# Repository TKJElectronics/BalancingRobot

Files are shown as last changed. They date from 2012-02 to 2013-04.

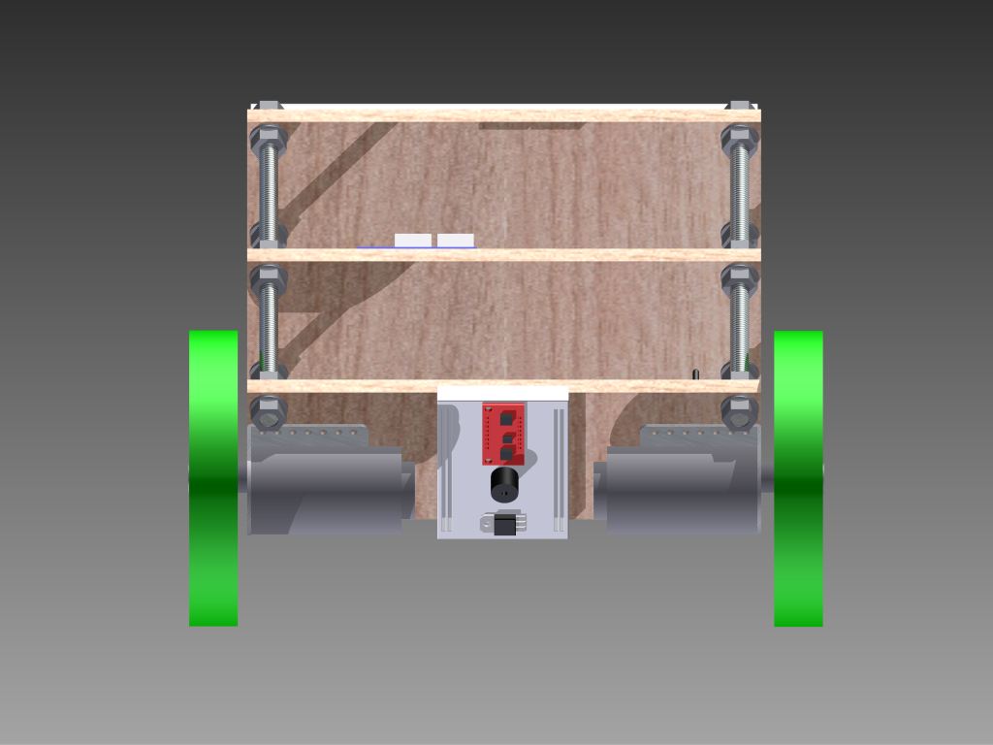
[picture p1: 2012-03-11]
3D Model/Rendered images/Back bottom.jpg

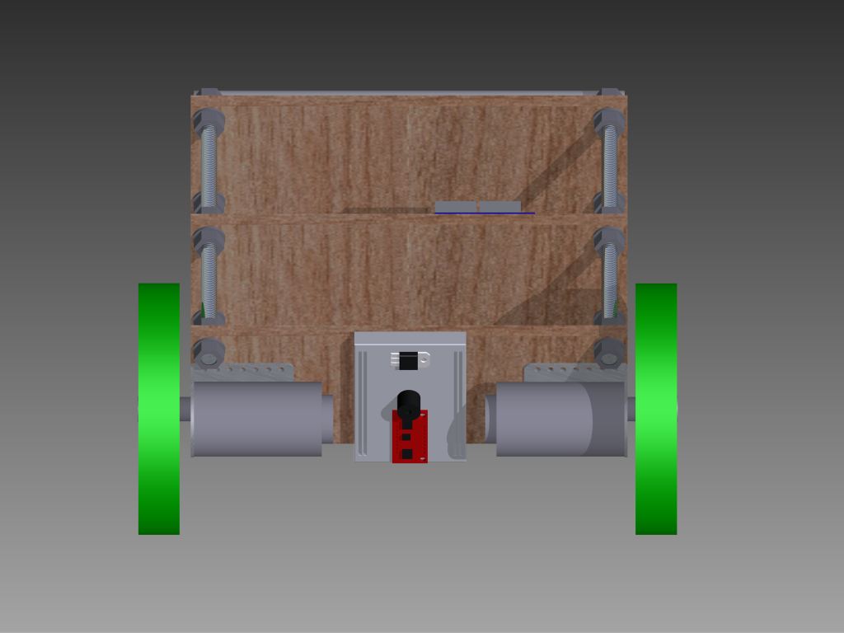
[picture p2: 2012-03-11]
3D Model/Rendered images/Front bottom.jpg

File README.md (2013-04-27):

# This project is deprecated

This project is no longer maintained as I will instead focus on a Balancing robot kit, the Balanduino. For more information see the new repository: <https://github.com/TKJElectronics/Balanduino> and the Kickstarter campaign: <http://www.kickstarter.com/projects/tkjelectronics/balanduino-balancing-robot-kit>.

<br>

The code is released under the GNU General Public License.
Developed by Kristian Lauszus

This is the code for my balancing robot/segway. It's made for the mbed board, but can easily be ported to other microcontrollers like the Arduino - see the Arduino version of the code: <https://github.com/TKJElectronics/BalancingRobotArduino>.

The code is also published on the mbed site: <http://mbed.org/users/Lauszus/programs/BalancingRobotPS3>.

I use a [6DOF IMU from Sparkfun](http://www.sparkfun.com/products/10010), I only use 1 of the gyro axis though.
For more info about calculating the pitch and the Kalman filter see my post at the Arduino forum: <http://arduino.cc/forum/index.php/topic,58048.0.html>.

To steer the robot, I use an Arduino with a [USB Host Shield](http://www.circuitsathome.com/products-page/arduino-shields/usb-host-shield-2-0-for-arduino/) on top together with my [PS3 Controller Bluetooth Library](https://github.com/felis/USB_Host_Shield_2.0/blob/master/PS3BT.cpp) for Arduino. The code for the remote can be found at my other repository: <https://github.com/TKJElectronics/BalancingRobotRemote>.

For information about the hardware, see the wiki: <https://github.com/TKJElectronics/BalancingRobot/wiki/Hardware>.

For more information see my blog post at <http://blog.tkjelectronics.dk/2012/03/the-balancing-robot/> or send me an email at: <kristianl@tkjelectronics.dk>.

Also check out the Youtube video of it in action: <http://www.youtube.com/watch?v=N28C_JqVhGU>.

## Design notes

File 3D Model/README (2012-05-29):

The code is released under the GNU General Public License.

This is the 3D model of my robot made in Autodesk Inventor 2012. See the folder "Rendered images" for images of the model.

The 3D model can also be viewed at the following site: http://grabcad.com/library/balancing-robot.

The Arduino board were made by the user "wam" at the Arduino forum: http://www.arduino.cc/cgi-bin/yabb2/YaBB.pl?num=1288144315/all.

The mbed board were made by Hugo Stoutjesdijk.

And the XBee module were made by Russell Donovan and downloaded from: http://grabcad.com/library/xbee-module.

For more information see my blog post at http://blog.tkjelectronics.dk/2012/02/the-balancing-robot/ or send me an email at kristianl at tkjelectronics dot dk.

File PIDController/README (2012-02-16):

The code is released under the GNU General Public License.

This is the code I used to find the proper PID values.
I used two XBee modules for wireless communication between a Processing (http://processing.org) application and the balancing robot. This enables me to change the PID values wirelessly without needing to reprogram the robot each time.

It really saved me A LOT of time, as it will take a while to find the optimal PID constants.

See the folder "Compiled versions" for double-clickable, standalone application for all major platforms: Linux, Windows, and Mac OS X.

For more information visit my blog at http://blog.tkjelectronics.dk/ or send me an email at kristianl at tkjelectronics dot dk.

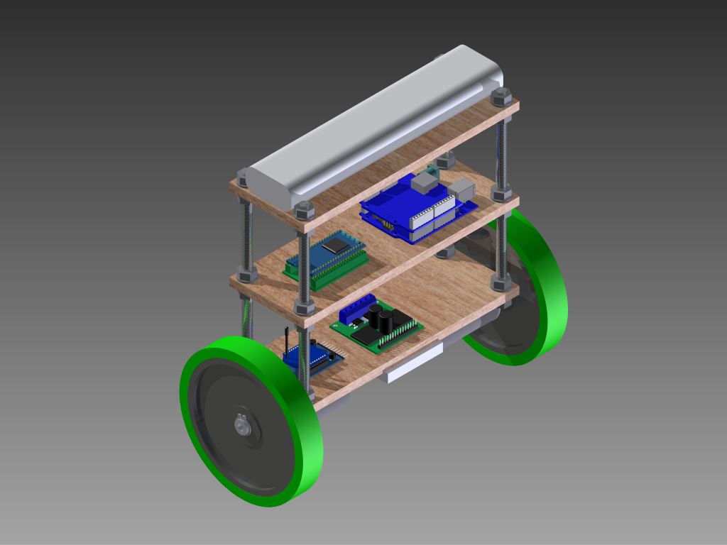
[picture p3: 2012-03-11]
3D Model/Rendered images/Front top left.jpg

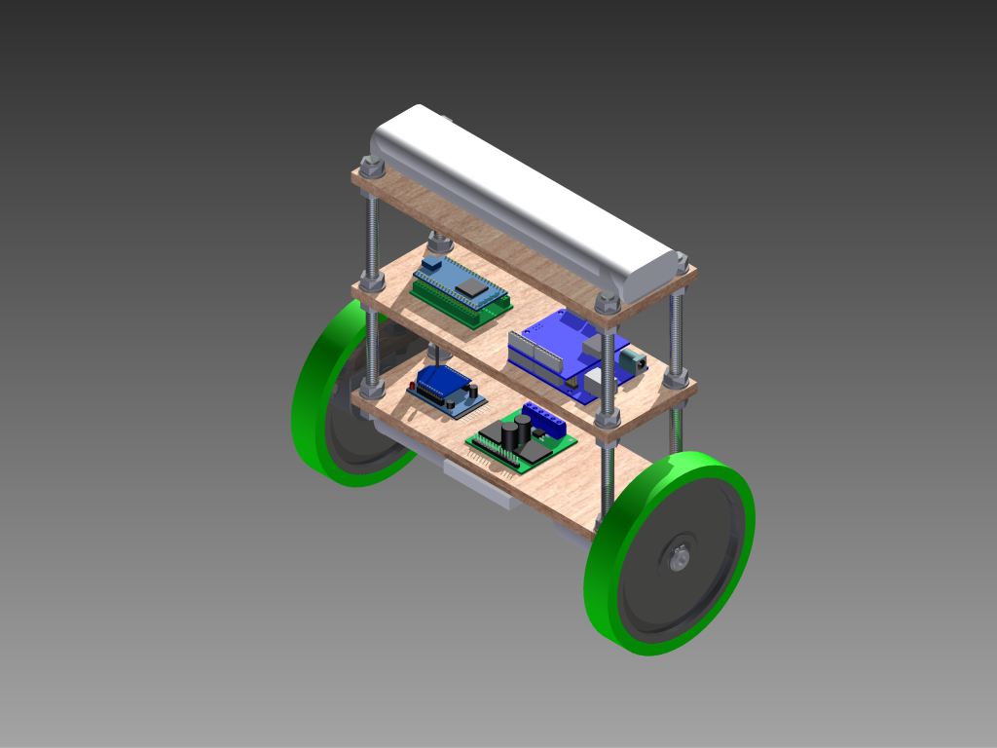
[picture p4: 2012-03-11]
3D Model/Rendered images/Front top right.jpg

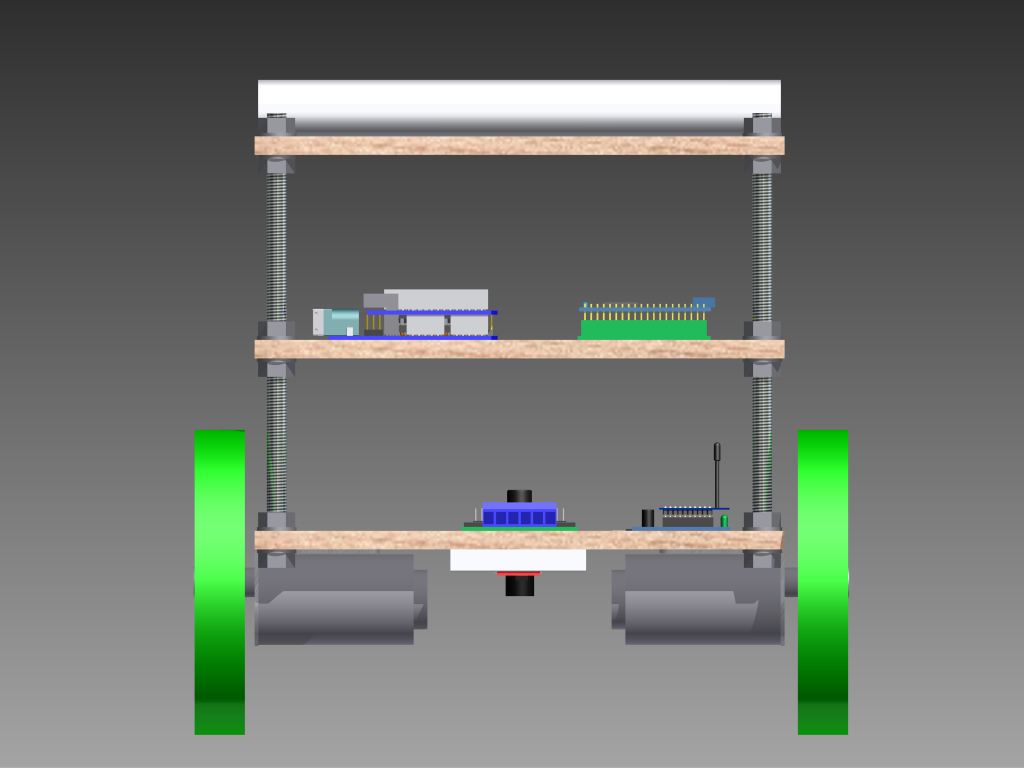
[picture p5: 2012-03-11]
3D Model/Rendered images/Back.jpg

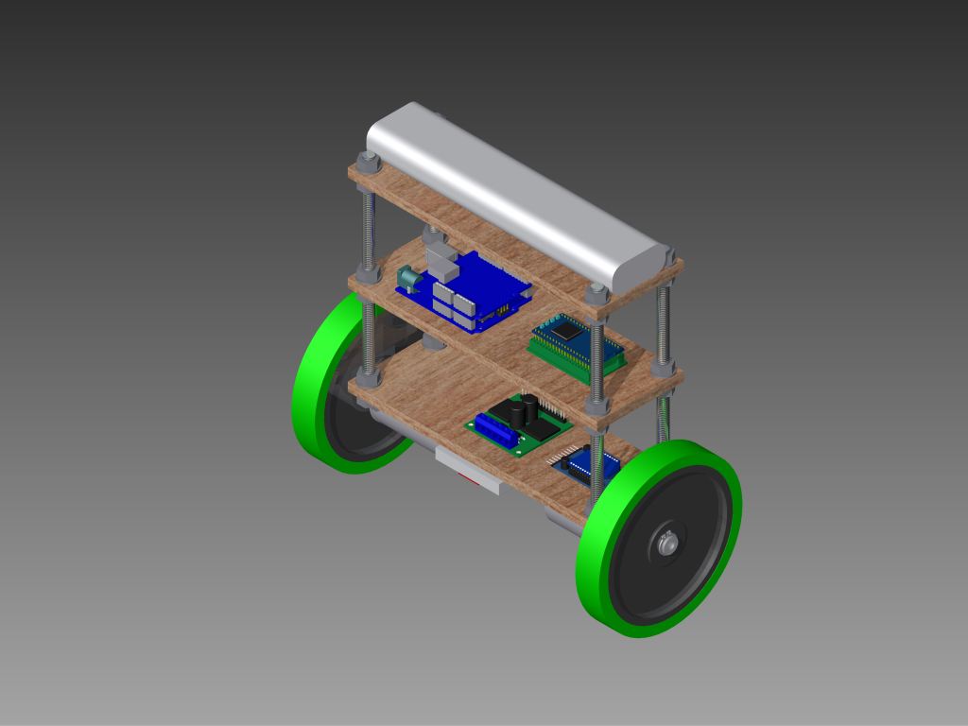
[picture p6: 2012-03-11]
3D Model/Rendered images/Back top right.jpg

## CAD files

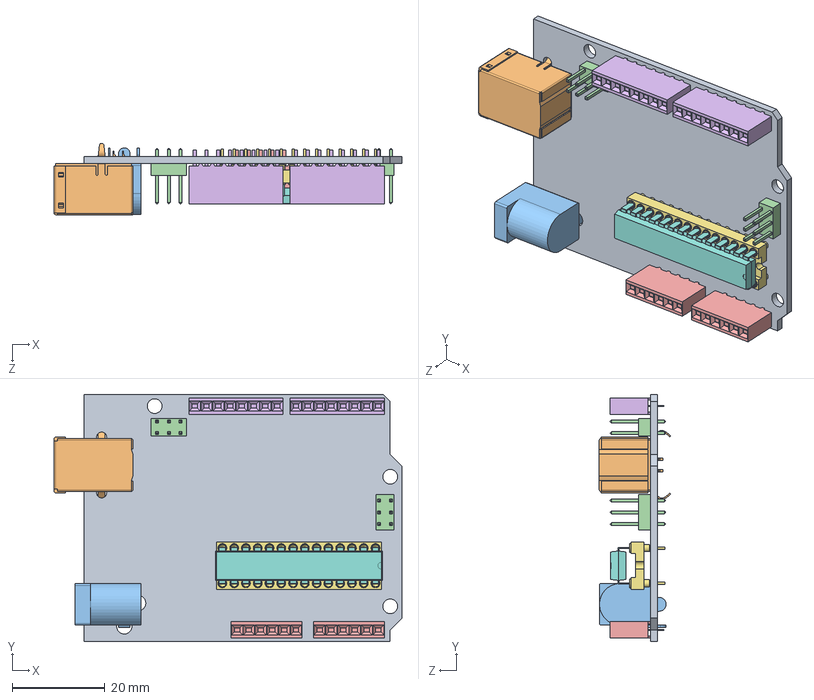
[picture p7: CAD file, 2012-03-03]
3D Model/uno-assy/uno-assy.SLDASM
75.0 x 53.3 x 15.4 mm
uno-pcb
SW3dPS-67068-0000-molex
RAPC732
3x2-100 x 2
C-0534237-04-3 x 2
C-0534237-06-3 x 2
28pdipskt
User Library-28 pin dip

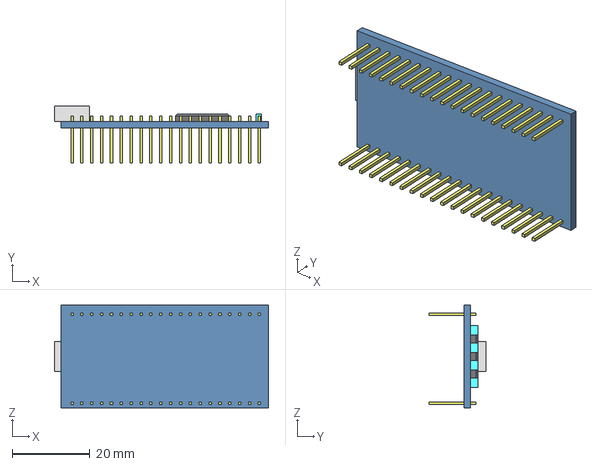
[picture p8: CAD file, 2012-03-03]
3D Model/mbedforum3dstepmodel/MBedPCB.stp
55.1 x 14.6 x 26.4 mm

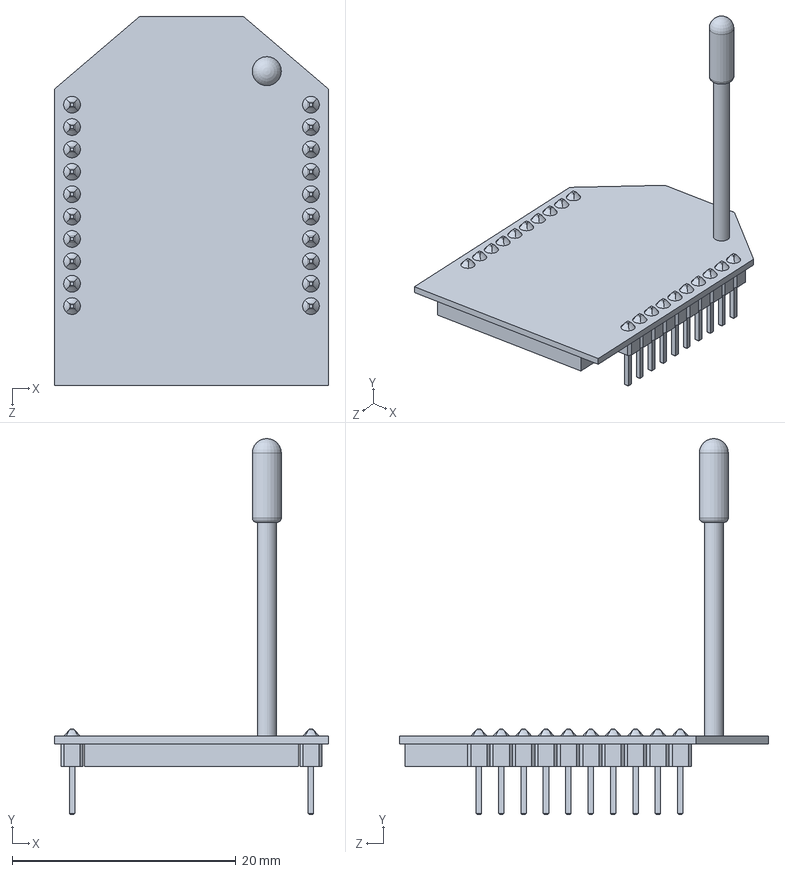
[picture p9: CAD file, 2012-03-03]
3D Model/XBee.SLDPRT
24.5 x 33.6 x 33.0 mm

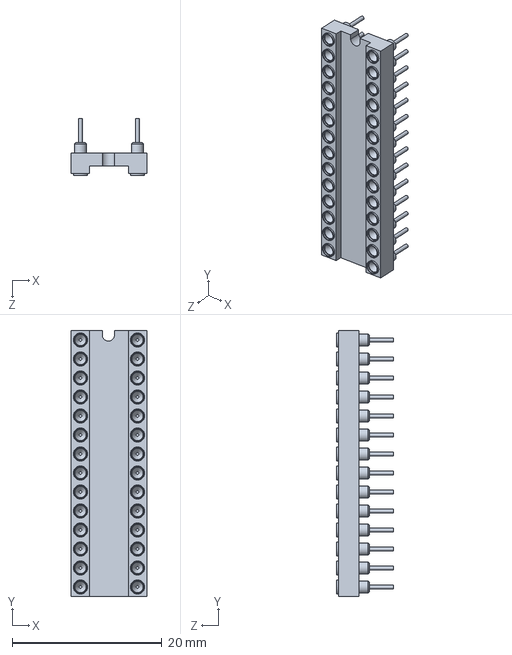
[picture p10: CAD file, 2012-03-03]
3D Model/uno-assy/28pdipskt.SLDPRT
10.2 x 35.6 x 7.62 mm

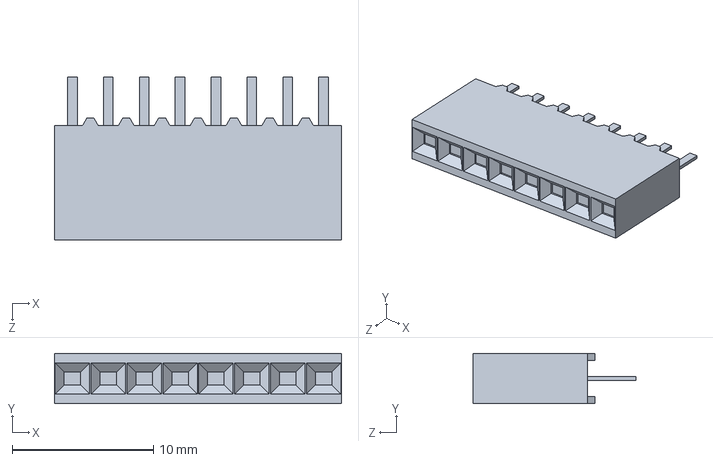
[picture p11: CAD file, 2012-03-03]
3D Model/uno-assy/C-0534237-06-3.SLDPRT
20.3 x 3.56 x 11.6 mm

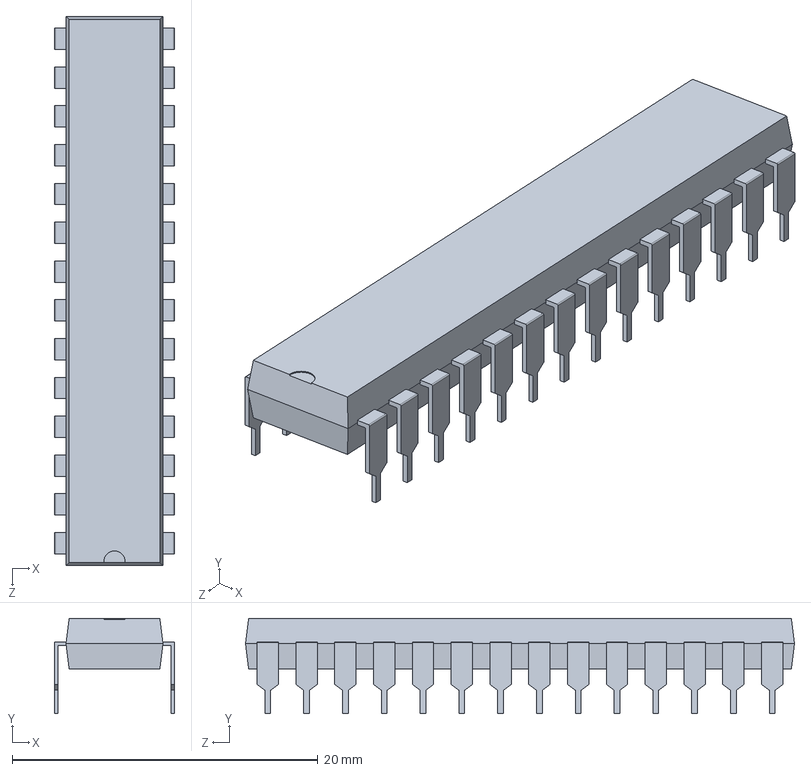
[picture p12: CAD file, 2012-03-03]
3D Model/uno-assy/User Library-28 pin dip.SLDPRT
7.87 x 6.22 x 35.9 mm

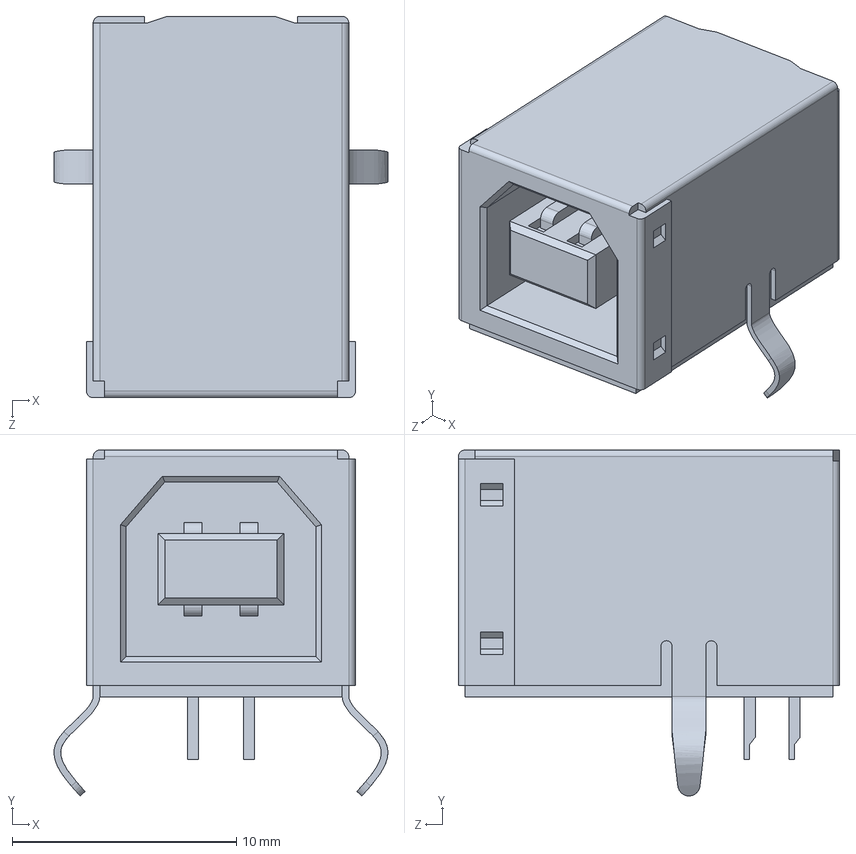
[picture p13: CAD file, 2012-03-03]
3D Model/uno-assy/SW3dPS-67068-0000-molex.SLDPRT
14.9 x 15.4 x 17.0 mm

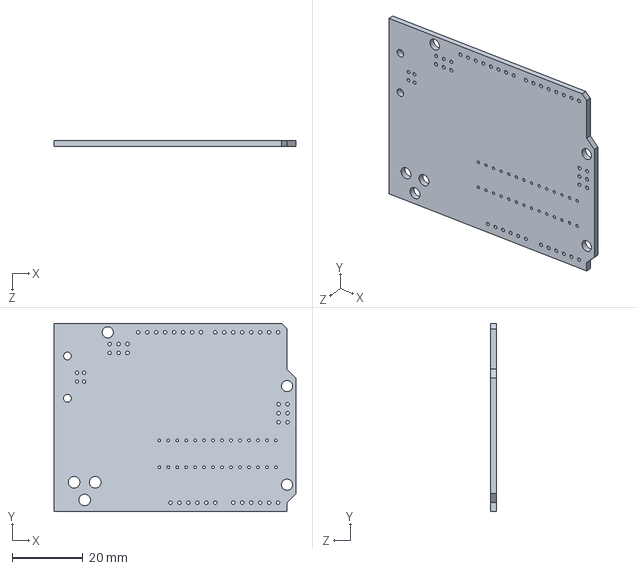
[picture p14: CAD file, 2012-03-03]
3D Model/uno-assy/uno-pcb.SLDPRT
68.6 x 53.3 x 1.59 mm

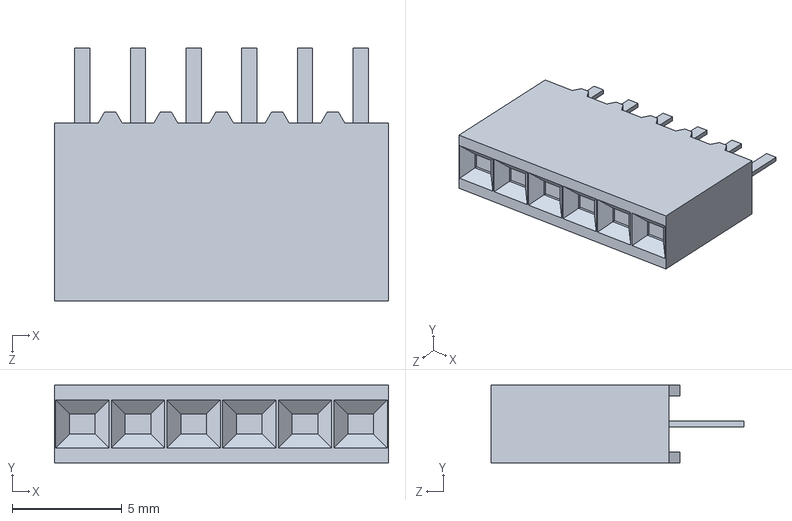
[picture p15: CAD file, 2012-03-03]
3D Model/uno-assy/C-0534237-04-3.SLDPRT
15.2 x 3.56 x 11.6 mm

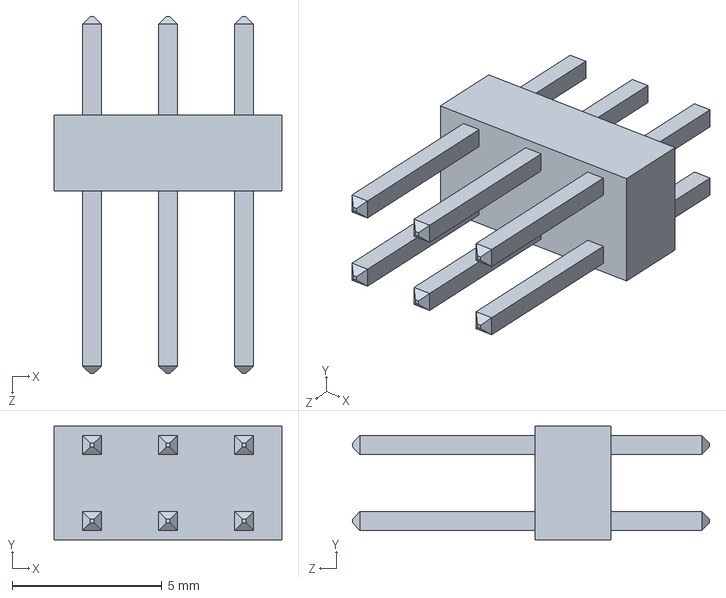
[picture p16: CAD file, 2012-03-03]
3D Model/uno-assy/3x2-100.SLDPRT
7.62 x 3.81 x 11.9 mm

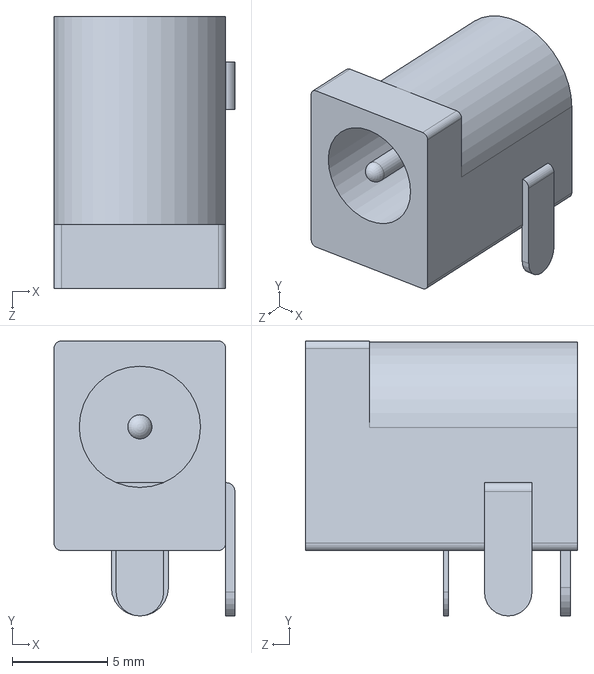
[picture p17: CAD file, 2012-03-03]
3D Model/uno-assy/RAPC732.sldprt
9.47 x 14.4 x 14.2 mm

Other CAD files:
3D Model/Adafruit xbee adapter.ipt
3D Model/Breadboard.ipt
3D Model/Breadboard_parts.ipt
3D Model/Hub.ipt
3D Model/IMU.ipt
3D Model/Imported Components/C-0534237-04-3/C-0534237-04-3.ipt
3D Model/Imported Components/C-0534237-06-3/C-0534237-06-3.ipt
3D Model/Imported Components/MBedPCB/MBedPCB.ipt
3D Model/Imported Components/XBee/OldVersions/XBee.0001.ipt
3D Model/Imported Components/XBee/XBee.ipt
3D Model/Imported Components/uno-assy/28pdipskt.ipt
3D Model/Imported Components/uno-assy/3x2-100.ipt
3D Model/Imported Components/uno-assy/C-0534237-04-3.ipt
3D Model/Imported Components/uno-assy/C-0534237-06-3.ipt
3D Model/Imported Components/uno-assy/OldVersions/uno-assy.0001.iam
3D Model/Imported Components/uno-assy/RAPC732.ipt
3D Model/Imported Components/uno-assy/SW3dPS-67068-0000-molex.ipt
3D Model/Imported Components/uno-assy/User Library-28 pin dip.ipt
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

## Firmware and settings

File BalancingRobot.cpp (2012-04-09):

/*
 * The code is released under the GNU General Public License.
 * Developed by Kristian Lauszus
 * This is the algorithm for my balancing robot/segway.
 * It is controlled by a PS3 Controller via bluetooth.
 * The remote control code can be found at my other github repository: https://github.com/TKJElectronics/BalancingRobot
 * For details, see http://blog.tkjelectronics.dk/2012/02/the-balancing-robot/
 */

#include "mbed.h"
#include "BalancingRobot.h"
#include "Encoder.h"

/* Setup serial communication */
Serial xbee(p13,p14); // For wireless debugging and setting PID constants
Serial ps3(p9,p10); // For remote control
Serial debug(USBTX, USBRX); // USB

/* Setup encoders */
Encoder leftEncoder(p29,p30);
Encoder rightEncoder(p28,p27);

/* Setup timer instance */
Timer t;

int main() {
    /* Set baudrate */
    xbee.baud(115200);
    ps3.baud(115200);
    debug.baud(115200);
    
    /* Set PWM frequency */
    leftPWM.period(0.00005); // The motor driver can handle a pwm frequency up to 20kHz (1/20000=0.00005)
    rightPWM.period(0.00005);
    
    /* Calibrate the gyro and accelerometer relative to ground */
    calibrateSensors();
    
    xbee.printf("Initialized\n");
    processing(); // Send output to processing application
    
    /* Setup timing */
    t.start();
    loopStartTime = t.read_us();
    timer = loopStartTime;
    
    while (1) {
        /* Calculate pitch */
        accYangle = getAccY();
        gyroYrate = getGyroYrate();
        
        // See my guide for more info about calculation the angles and the Kalman filter: http://arduino.cc/forum/index.php/topic,58048.0.html
        pitch = kalman(accYangle, gyroYrate, t.read_us() - timer); // calculate the angle using a Kalman filter
        timer = t.read_us();
        
        //debug.printf("Pitch: %f, accYangle: %f\n",pitch,accYangle);
        
        /* Drive motors */
        if (pitch < 60 || pitch > 120) // Stop if falling or laying down
            stopAndReset();
        else
            PID(targetAngle,targetOffset);
        
        /* Update wheel velocity every 100ms */
        loopCounter++;
        if (loopCounter%10 == 0) { // If remainder is equal 0, it must be 10,20,30 etc.
            //xbee.printf("Wheel - timer: %i\n",t.read_ms());
            wheelPosition = leftEncoder.read() + rightEncoder.read();
            wheelVelocity = wheelPosition - lastWheelPosition;
            lastWheelPosition = wheelPosition;
            //xbee.printf("WheelVelocity: %i\n",wheelVelocity);
            
            if (abs(wheelVelocity) <= 20 && !stopped) { // Set new targetPosition if breaking
                targetPosition = wheelPosition;
                stopped = true;
                //xbee.printf("Stopped\n");
            }
        }
        
        /* Check for incoming serial data */
        if (ps3.readable()) // Check if there's any incoming data
            receivePS3();
        if (xbee.readable()) // For setting the PID values
            receiveXbee();
        
        /* Read battery voltage every 1s */
        if (loopCounter == 100) {
            loopCounter = 0; // Reset loop counter
            double analogVoltage = batteryVoltage.read()/1*3.3; // Convert to voltage
            analogVoltage *= 6.6; // The analog pin is connected to a 56k-10k voltage divider
            xbee.printf("analogVoltage: %f - timer: %i\n",analogVoltage,t.read_ms());
            if (analogVoltage < 9 && pitch > 60 && pitch < 120) // Set buzzer on, if voltage gets critical low
                buzzer = 1; // The mbed resets at aproximatly 8.5V
        }
        
        /* Use a time fixed loop */
        lastLoopUsefulTime = t.read_us() - loopStartTime;
        if (lastLoopUsefulTime < STD_LOOP_TIME)
            wait_us(STD_LOOP_TIME - lastLoopUsefulTime);
        lastLoopTime = t.read_us() - loopStartTime; // only used for debugging
        loopStartTime = t.read_us();
        
        //debug.printf("%i,%i\n",lastLoopUsefulTime,lastLoopTime);
    }
}
void PID(double restAngle, double offset) {
    /* Steer robot */
    if (steerForward) {
        offset += (double)wheelVelocity/velocityScaleMove; // Scale down offset at high speed and scale up when reversing
        restAngle -= offset;
        //xbee.printf("Forward offset: %f\t WheelVelocity: %i\n",offset,wheelVelocity);
    } else if (steerBackward) {
        offset -= (double)wheelVelocity/velocityScaleMove; // Scale down offset at high speed and scale up when reversing
        restAngle += offset;
        //xbee.printf("Backward offset: %f\t WheelVelocity: %i\n",offset,wheelVelocity);
    }
    /* Break */
    else if (steerStop) {
        long positionError = wheelPosition - targetPosition;
        if (abs(positionError) > zoneA) // Inside zone A
            restAngle -= (double)positionError/positionScaleA;
        else if (abs(positionError) > zoneB) // Inside zone B
            restAngle -= (double)positionError/positionScaleB;
        else // Inside zone C
            restAngle -= (double)positionError/positionScaleC;
        
        restAngle -= (double)wheelVelocity/velocityScaleStop;
        
        if (restAngle < 80) // Limit rest Angle
            restAngle = 80;
        else if (restAngle > 100)
            restAngle = 100;
        //xbee.printf("restAngle: %f\t WheelVelocity: %i positionError: %i\n",restAngle,wheelVelocity,positionError);
    }
    /* Update PID values */
    double error = (restAngle - pitch)/100;
    double pTerm = Kp * error;
    iTerm += Ki * error;
    double dTerm = Kd * (error - lastError);
    lastError = error;
    
    double PIDValue = pTerm + iTerm + dTerm;
    
    //debug.printf("Pitch: %5.2f\tPIDValue:  %5.2f\tpTerm: %5.2f\tiTerm: %5.2f\tdTerm: %5.2f\tKp: %5.2f\tKi: %5.2f\tKd: %5.2f\n",pitch,PIDValue,pTerm,iTerm,dTerm,Kp,Ki,Kd);
    
    /* Steer robot sideways */
    double PIDLeft;
    double PIDRight;
    if (steerLeft) {
        PIDLeft = PIDValue-turnSpeed;
        PIDRight = PIDValue+turnSpeed;
    } else if (steerRotateLeft) {
        PIDLeft = PIDValue-rotateSpeed;
        PIDRight = PIDValue+rotateSpeed;
    } else if (steerRight) {
        PIDLeft = PIDValue+turnSpeed;
        PIDRight = PIDValue-turnSpeed;
    } else if (steerRotateRight) {
        PIDLeft = PIDValue+rotateSpeed;
        PIDRight = PIDValue-rotateSpeed;
    } else {
        PIDLeft = PIDValue;
        PIDRight = PIDValue;
    }
    PIDLeft *= 0.95; // compensate for difference in the motors
    
    /* Set PWM Values */
    if (PIDLeft >= 0)
        move(left, forward, PIDLeft);
    else
        move(left, backward, PIDLeft * -1);
    if (PIDRight >= 0)
        move(right, forward, PIDRight);
    else
        move(right, backward, PIDRight * -1);
}
void receivePS3() {
    char input[16]; // The serial buffer is only 16 characters
    int i = 0;
    while (1) {
        input[i] = ps3.getc();
        if (input[i] == ';' || i == 15) // keep reading until it reads a semicolon or it exceeds the serial buffer
            break;
        i++;
    }
    //debug.printf("Input: %s\n",input);
    
    // Set all false
    steerForward = false;
    steerBackward = false;
    steerStop = false;
    steerLeft = false;
    steerRotateLeft = false;
    steerRight = false;
    steerRotateRight = false;
    
    /* For remote control */
    if (input[0] == 'F') { // Forward
        strtok(input, ","); // Ignore 'F'
        targetOffset = atof(strtok(NULL, ";")); // read until the end and then convert from string to double
        //xbee.printf("%f\n",targetOffset); // Print targetOffset for debugging
        steerForward = true;
    } else if (input[0] == 'B') { // Backward
        strtok(input, ","); // Ignore 'B'
        targetOffset = atof(strtok(NULL, ";")); // read until the end and then convert from string to double
        //xbee.printf("%f\n",targetOffset); // Print targetOffset for debugging
        steerBackward = true;
    } else if (input[0] == 'L') { // Left
        if (input[1] == 'R') // Left Rotate
            steerRotateLeft = true;
        else
            steerLeft = true;
    } else if (input[0] == 'R') { // Right
        if (input[1] == 'R') // Right Rotate
            steerRotateRight = true;
        else
            steerRight = true;
    } else if (input[0] == 'S') { // Stop
        steerStop = true;
        stopped = false;
        targetPosition = wheelPosition;
    }
    
    else if (input[0] == 'T') { // Set the target angle
        strtok(input, ","); // Ignore 'T'
        targetAngle = atof(strtok(NULL, ";")); // read until the end and then convert from string to double
        xbee.printf("%f\n",targetAngle); // Print targetAngle for debugging
    } else if (input[0] == 'A') { // Abort
        stopAndReset();
        while (ps3.getc() != 'C'); // Wait until continue is send
    }
}
void receiveXbee() {
    char input[16]; // The serial buffer is only 16 characters
    int i = 0;
    while (1) {
        input[i] = xbee.getc();
        if (input[i] == ';' || i == 15) // keep reading until it reads a semicolon or it exceeds the serial buffer
            break;
        i++;
    }
    //debug.printf("Input: %s\n",input);
    
    if (input[0] == 'T') { // Set the target angle
        strtok(input, ","); // Ignore 'T'
        targetAngle = atof(strtok(NULL, ";")); // read until the end and then convert from string to double
    } else if (input[0] == 'P') {
        strtok(input, ",");//Ignore 'P'
        Kp = atof(strtok(NULL, ";")); // read until the end and then convert from string to double
    } else if (input[0] == 'I') {
        strtok(input, ",");//Ignore 'I'
        Ki = atof(strtok(NULL, ";")); // read until the end and then convert from string to double
    } else if (input[0] == 'D') {
        strtok(input, ",");//Ignore 'D'
        Kd = atof(strtok(NULL, ";")); // read until the end and then convert from string to double
    } else if (input[0] == 'A') { // Abort
        stopAndReset();
        while (xbee.getc() != 'C'); // Wait until continue is send
    } else if (input[0] == 'G') // The processing application sends this at startup
        processing(); // Send output to processing application
}
void processing() {
    /* Send output to processing application */
    xbee.printf("Processing,%5.2f,%5.2f,%5.2f,%5.2f\n",Kp,Ki,Kd,targetAngle);
}
void stopAndReset() {
    stop(both);
    lastError = 0;
    iTerm = 0;
    targetPosition = wheelPosition;
    buzzer = 0;
}
double kalman(double newAngle, double newRate, double dtime) {
    // KasBot V2  -  Kalman filter module - http://www.arduino.cc/cgi-bin/yabb2/YaBB.pl?num=1284738418 - http://www.x-firm.com/?page_id=145
    // with slightly modifications by Kristian Lauszus
    // See http://academic.csuohio.edu/simond/courses/eec644/kalman.pdf and http://www.cs.unc.edu/~welch/media/pdf/kalman_intro.pdf for more information
    dt = dtime / 1000000; // Convert from microseconds to seconds
    
    // Discrete Kalman filter time update equations - Time Update ("Predict")
    // Update xhat - Project the state ahead
    angle += dt * (newRate - bias);
    
    // Update estimation error covariance - Project the error covariance ahead
    P_00 += -dt * (P_10 + P_01) + Q_angle * dt;
    P_01 += -dt * P_11;
    P_10 += -dt * P_11;
    P_11 += +Q_gyro * dt;
    
    // Discrete Kalman filter measurement update equations - Measurement Update ("Correct")
    // Calculate Kalman gain - Compute the Kalman gain
    S = P_00 + R_angle;
    K_0 = P_00 / S;
    K_1 = P_10 / S;
    
    // Calculate angle and resting rate - Update estimate with measurement zk
    y = newAngle - angle;
    angle += K_0 * y;
    bias += K_1 * y;
    
    // Calculate estimation error covariance - Update the error covariance
    P_00 -= K_0 * P_00;
    P_01 -= K_0 * P_01;
    P_10 -= K_1 * P_00;
    P_11 -= K_1 * P_01;
    
    return angle;
}
double getGyroYrate() {
    // (gyroAdc-gyroZero)/Sensitivity (In quids) - Sensitivity = 0.00333/3.3=0.001009091
    double gyroRate = -((gyroY.read() - zeroValues[0]) / 0.001009091);
    return gyroRate;
}
double getAccY() {
    // (accAdc-accZero)/Sensitivity (In quids) - Sensitivity = 0.33/3.3=0.1
    double accXval = (accX.read() - zeroValues[1]) / 0.1;
    double accYval = (accY.read() - zeroValues[2]) / 0.1;
    accYval--;//-1g when lying down
    double accZval = (accZ.read() - zeroValues[3]) / 0.1;
    
    double R = sqrt(pow(accXval, 2) + pow(accYval, 2) + pow(accZval, 2)); // Calculate the length of force vector
    double angleY = acos(accYval / R) * RAD_TO_DEG;
    
    return angleY;
}
void calibrateSensors() {
    LEDs = 0xF; // Turn all onboard LEDs on
    
    double adc[4] = {0,0,0,0};
    for (uint8_t i = 0; i < 100; i++) { // Take the average of 100 readings
        adc[0] += gyroY.read();
        adc[1] += accX.read();
        adc[2] += accY.read();
        adc[3] += accZ.read();
        wait_ms(10);
    }
    zeroValues[0] = adc[0] / 100; // Gyro X-axis
    zeroValues[1] = adc[1] / 100; // Accelerometer X-axis
    zeroValues[2] = adc[2] / 100; // Accelerometer Y-axis
    zeroValues[3] = adc[3] / 100; // Accelerometer Z-axis
    
    LEDs = 0x0; // Turn all onboard LEDs off
}
void move(Motor motor, Direction direction, float speed) { // speed is a value in percentage (0.0f to 1.0f)
    if (motor == left) {
        leftPWM = speed;
        if (direction == forward) {
            leftA = 0;
            leftB = 1;
        } else if (direction == backward) {
            leftA = 1;
            leftB = 0;
        }
    } else if (motor == right) {
        rightPWM = speed;
        if (direction == forward) {
            rightA = 0;
            rightB = 1;
        } else if (direction == backward) {
            rightA = 1;
            rightB = 0;
        }
    } else if (motor == both) {
        leftPWM = speed;
        rightPWM = speed;
        if (direction == forward) {
            leftA = 0;
            leftB = 1;
            
            rightA = 0;
            rightB = 1;
        } else if (direction == backward) {
            leftA = 1;
            leftB = 0;
            
            rightA = 1;
            rightB = 0;
        }
    }
}
void stop(Motor motor) {
    if (motor == left) {
        leftPWM = 1;
        leftA = 1;
        leftB = 1;
    } else if (motor == right) {
        rightPWM = 1;
        rightA = 1;
        rightB = 1;
    } else if (motor == both) {
        leftPWM = 1;
        leftA = 1;
        leftB = 1;
        
        rightPWM = 1;
        rightA = 1;
        rightB = 1;
    }
}

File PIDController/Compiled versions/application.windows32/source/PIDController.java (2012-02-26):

import processing.core.*; 
import processing.xml.*; 

import processing.serial.*; 
import controlP5.*; 

import java.applet.*; 
import java.awt.Dimension; 
import java.awt.Frame; 
import java.awt.event.MouseEvent; 
import java.awt.event.KeyEvent; 
import java.awt.event.FocusEvent; 
import java.awt.Image; 
import java.io.*; 
import java.net.*; 
import java.text.*; 
import java.util.*; 
import java.util.zip.*; 
import java.util.regex.*; 

public class PIDController extends PApplet {

  

ControlP5 controlP5;

Textfield P;
Textfield I;
Textfield D;
Textfield targetAngle;

String stringP = "";
String stringI = "";
String stringD = "";
String stringTargetAngle = "";

PFont f;

boolean useDropDownLists = true; // Set if you want to use the dropdownlist or not
byte defaultComPort = 0;
int defaultBaudrate = 115200;

//Dropdown lists
DropdownList COMports; // Define the variable ports as a Dropdownlist.
Serial xbee; // Define the variable port as a Serial object.
int portNumber = -1; // The dropdown list will return a float value, which we will connvert into an int. We will use this int for that.

DropdownList baudrate;
int selectedBaudrate = -1; // Used to indicate which baudrate has been selected
String[] baudrates = {
  "1200", "2400", "4800", "9600", "19200", "38400", "57600", "115200" // these are the supported baudrates by a xbee module
};
boolean connectedSerial;
boolean aborted;

public void setup()
{
  controlP5 = new ControlP5(this);
  size(337, 230);

  f = loadFont("EuphemiaUCAS-Bold-30.vlw");
  textFont(f, 30);
  
  P = controlP5.addTextfield("P", 10, 65, 35, 20);
  P.setFocus(true);
  I = controlP5.addTextfield("I", 50, 65, 35, 20);
  D = controlP5.addTextfield("D", 90, 65, 35, 20);
  targetAngle = controlP5.addTextfield("TargetAngle", 130, 65, 35, 20);

  P.setAutoClear(false);
  I.setAutoClear(false);
  D.setAutoClear(false);
  targetAngle.setAutoClear(false);

  P.clear();
  I.clear();
  D.clear();
  targetAngle.clear();

  controlP5.addButton("Submit", 0, 202, 65, 60, 20);
  controlP5.addButton("Clear", 0, 267, 65, 60, 20);

  controlP5.addButton("Abort", 0, 10, 200, 40, 20);
  controlP5.addButton("Continue", 0, 55, 200, 50, 20);
  controlP5.addButton("StoreValues", 0, 267, 200, 60, 20);

  //println(xbee.list()); // Used for debugging
  if (useDropDownLists)
  {
    /* Drop down lists */
    COMports = controlP5.addDropdownList("COMPort", 10, 20, 150, 200); // Make a dropdown list with all comports
    customize(COMports); // Setup the dropdownlist by using a function

    baudrate = controlP5.addDropdownList("Baudrate", 165, 20, 55, 200); // Make a dropdown with all the available baudrates   
    customize(baudrate); // Setup the dropdownlist by using a function

    controlP5.addButton("Connect", 0, 225, 3, 45, 15);
    controlP5.addButton("Disconnect", 0, 275, 3, 52, 15);
  }
  else // if useDropDownLists is false, it will connect automatically at startup
  {
    xbee = new Serial(this, Serial.list()[defaultComPort], defaultBaudrate);
    xbee.bufferUntil('\n');
    connectedSerial = true;
    xbee.write("G;"); // Go
  }
}

public void draw() 
{
  background(0);

  fill(0, 102, 153);
  textSize(30); 
  textAlign(CENTER); 
  text("Set PID Values:", width/2, 55);
  text("Current PID Values:", width/2, 150);

  fill(255, 255, 255);
  textSize(10);  
  textAlign(LEFT);
  text("P: " + stringP + " I: " + stringI +  " D: " + stringD + " TargetAngle: " + stringTargetAngle, 10, 175); // Motor
}
public void Abort(int theValue)
{
  if (connectedSerial) 
  {
    xbee.write("A;");
    aborted = true;
  }
  else
    println("Establish a serial connection first!");
}
public void Continue(int theValue)
{
  if (connectedSerial) 
  {
    xbee.write("C;");
    aborted = false;
  }
  else
    println("Establish a serial connection first!");
}
public void Submit(int theValue) 
{
  if (connectedSerial)
  {    
    println("PID values: " + P.getText() + " " + I.getText() + " " + D.getText() +  " TargetAnlge: " + targetAngle.getText());
    String output1 = "P," + P.getText() + ';';
    String output2 = "I," + I.getText() + ';';
    String output3 = "D," + D.getText() + ';';
    String output4 = "T," + targetAngle.getText() + ';';

    xbee.write(output1);
    delay(10);
    xbee.write(output2);
    delay(10);
    xbee.write(output3);
    delay(10);
    xbee.write(output4);
    delay(10);    
    xbee.write("G;"); // Send values back to application
    delay(10);    
  }
  else
    println("Establish a serial connection first!");
}
public void Clear(int theValue) 
{
  P.clear();
  I.clear();
  D.clear();
  targetAngle.clear();
}
public void StoreValues(int theValue)
{
  //Don't set the text if the string is empty or it will crash
  if (stringP != null)
    P.setText(stringP);
  if (stringI != null)
    I.setText(stringI);
  if (stringD != null)
    D.setText(stringD);
  if (stringTargetAngle != null)
    targetAngle.setText(stringTargetAngle);
}
public void serialEvent(Serial xbee)
{
  String[] input = trim(split(xbee.readString(), ','));
  for (int i = 0; i<input.length;i++)
    println("Number: " + i + " Input: " + input[i]); // For debugging

  if (input[0].equals("Initialized"))
    println("Started");
  else if(input[0].equals("Processing"))
  {    
    if (input[1].length() > 5)
      stringP = input[1].substring(0, 5);
    else
      stringP = input[1];
    if (input[2].length() > 5)
      stringI = input[2].substring(0, 5);
    else
      stringI = input[2];
    if (input[3].length() > 5)
      stringD = input[3].substring(0, 5);
    else
      stringD = input[3];
    if (input[4].length() > 5)
      stringTargetAngle = input[4].substring(0, 5);
    else
      stringTargetAngle = input[4];
  }
  else
    println(input[0]);
  xbee.clear();  // Empty the buffer
}
public void keyPressed() 
{
  if (key == TAB)//'\t'
  {
    if (P.isFocus())
    {
      P.setFocus(false);
      I.setFocus(true);
    }
    else if (I.isFocus())
    {
      I.setFocus(false);
      D.setFocus(true);
    }
    else if (D.isFocus())
    {
      D.setFocus(false);
      targetAngle.setFocus(true);
    }
    else if (targetAngle.isFocus())
    {
      targetAngle.setFocus(false);
      P.setFocus(true);
    }    
    else
      P.setFocus(true);
  }
  else if (key == ENTER) // '\n'
    Submit(0);
  else if (key == ESC)
  {
    if (aborted)
      Continue(0);
    else
      Abort(0);      
    key = 0; // Disable Processing from quiting when pressing ESC
  }
  else if (key == CODED)
  {
    if (keyCode == UP)
      StoreValues(0);
  }
}
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

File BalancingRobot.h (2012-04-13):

#ifndef _balancingrobot_h_
#define _balancingrobot_h_

#define RAD_TO_DEG 57.295779513082320876798154814105 // 180/pi

BusOut LEDs(LED1, LED2, LED3, LED4);

/* Left motor */
DigitalOut leftA(p21);
DigitalOut leftB(p22);
PwmOut leftPWM(p23);

/* Right motor */
DigitalOut rightA(p24);
DigitalOut rightB(p25);
PwmOut rightPWM(p26);

/* IMU */
AnalogIn gyroY(p17);
AnalogIn accX(p18);
AnalogIn accY(p19);
AnalogIn accZ(p20);

/* Battery voltage */
AnalogIn batteryVoltage(p15); // The analog pin is connected to a 56k-10k voltage divider
DigitalOut buzzer(p5); // Connected to a BC547 transistor - there is a protection diode at the buzzer 

// Zero voltage values for the sensors - [0] = gyroY, [1] = accX, [2] = accY, [3] = accZ
double zeroValues[4];

/* Kalman filter variables and constants */
const float Q_angle = 0.001; // Process noise covariance for the accelerometer - Sw
const float Q_gyro = 0.003; // Process noise covariance for the gyro - Sw
const float R_angle = 0.03; // Measurement noise covariance - Sv

double angle = 180; // It starts at 180 degrees
double bias = 0;
double P_00 = 0, P_01 = 0, P_10 = 0, P_11 = 0;
double dt, y, S;
double K_0, K_1;

// Results
double accYangle;
double gyroYrate;
double pitch;

/* PID variables */
double Kp = 8; //11 - 7
double Ki = 2; //1
double Kd = 9; //12
double targetAngle = 90;

double lastError;
double iTerm;

/* Used for timing */
unsigned long timer;

const long STD_LOOP_TIME = 10*1000; // Fixed time loop of 10 milliseconds
long lastLoopTime = STD_LOOP_TIME;
long lastLoopUsefulTime = STD_LOOP_TIME;
long loopStartTime;

enum Motor {
    left,
    right,
    both,
};
enum Direction {
    forward,
    backward,
};

bool steerForward;
bool steerBackward;
bool steerStop = true; // Stop by default
bool steerLeft;
bool steerRotateLeft;
bool steerRight;
bool steerRotateRight;

bool stopped;

const double turnSpeed = 0.1;
const double rotateSpeed = 0.2;

double targetOffset = 0;

uint8_t loopCounter = 0; // Used for wheel velocity and battery voltage
long wheelPosition;
long lastWheelPosition;
long wheelVelocity;
long targetPosition;
int zoneA = 4000; // 2000
int zoneB = 2000; // 1000
double positionScaleA = 250; // one resolution is 464 pulses
double positionScaleB = 500; 
double positionScaleC = 1000;
double velocityScaleMove = 40;
double velocityScaleStop = 30;//30 - 40 - 60

void calibrateSensors();
void PID(double restAngle, double offset);
double kalman(double newAngle, double newRate, double looptime);
double getGyroYrate();
double getAccY();
void move(Motor motor, Direction direction, float speed);
void stop(Motor motor);
void processing();
void receivePS3();
void receiveXbee();
void stopAndReset();

#endif

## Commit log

2012-02-14 Added the program I used to find the PID values
2012-02-26 Implemented encoders
2012-03-02 Added battery alarm
2012-03-03 Added 3D model
    [28pdipskt.SLDPRT, 28pdipskt.ipt, 3x2-100.SLDPRT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]
2012-03-03 Changed all names to english words
    [Segway.0055.iam, Segway.0056.iam, Segway.iam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]
2012-03-03 Fixed name
    [Segway.0056.iam, Segway.0057.iam, Segway.iam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]
2012-03-04 Fixed names
    [Screw bar.ipt, Segway.0029.iam, Segway.0057.iam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]
2012-03-06 Fixed wheel dimensions
    [Segway.0058.iam, Segway.0063.iam, Segway.iam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]
2012-03-06 Adjusted buzzer voltage
2012-03-11 Modified colors
    [Adafruit xbee adapter.0001.ipt, Adafruit xbee adapter.0006.ipt, Adafruit xbee adapter.0007.ipt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]
2012-04-13 Fixed timer to unsigned long
    [BalancingRobot.h]
2012-04-15 Added link to Arduino version
2012-04-26 Added CAD files
